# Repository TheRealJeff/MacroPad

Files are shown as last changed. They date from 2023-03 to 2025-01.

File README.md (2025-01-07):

# MacroPad
This page outlines the MacroPad V1 keyboard project. This keyboard is a custom made 4x3 (rxc) with hotswap MX style switches based on the ATMEGA32U4 MCU platform. It is powered by a built-in USB-C connector and uses a custom firmware designed and uploaded with QMK (QMK MSYS and QMK Toolbox). All the required files for PCB, Mech and Firmware are found here.

- '\PCB': kicad, BOM, GERBERS files
- '\3D': Mech design files
- '\firmware': keymaps, configs and hex files

## PCB Design
The PCB was fully designed with KiCAD 7, uses the keyswitch libraries from [ai03 Custom Keyboard](https://wiki.ai03.com/books/pcb-design) and is based on the design from [Masterzen's Blog](https://www.masterzen.fr/2020/05/03/designing-a-keyboard-part-1/).

The keyboard uses an ATMEGA32U4 to receive inputs from a 4x3 key switch matrix. The keyboard uses a USB-C over a USB 2.0 interface for power and data. The switches have Kailh hot swap sockets for easy swapping of the key switches.

## Mech Design
The keyboard has a basic enclosure designed to mainly give it a flat support for testing. It is mounted with 4 M2.5x4mm screws for stability. Currently, the key switches are only retained by the hot swap sockets.

## Firmware
QMK was used for the custom keymap (key switch layout).  Currently, the layout has the following keymap:
| ESC | DEL | 0 |
|-----|-----|---|
| 7 | 8 | 9 |
| 4 | 5 | 6 |
| 1 | 2 | 3 |

### Keyboard Programming
Download QMK MSYS and QMK Toolbox. Open QMK MSYS and follow the on screen instructions to download the necessary repos and drivers.

The `firmware\macropadv1` folder must be put in the `qmk_firmware\keyboards` folder downloaded and installed by QMK MSYS.

To create a new keymap, simply make a new folder in `macropadv1\keymap`, copy the default keymap file and modify it. In QMK MSYS, use the command `qmk compile -kb <keyboard> -km <keymap>` with the selected `keyboard` and `keymap`.

To upload the created `.hex` file, use QMK Toolbox. Connect the keyboard, and press on the reset button. The Toolbox window should display a "DFU Mode" message. At this point, select the `.hex` and flash the keyboard.

## Future Work
Future revisions will have the following updates:
- Use the RP2040 MCU
- LEDs
- Different key matrices
	- 1x2 for OSU
	- Numpad
	- TKL
	- Split keyboard layout (see ZSA Moonlander)
	- Alice Layout
- Better software update for keymaps
- Redesigned enclosure for plate mount switches

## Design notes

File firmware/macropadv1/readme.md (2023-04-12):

# macropadv1

macropadv1

*A short description of the keyboard/project*

* Keyboard Maintainer: [Jeffrey](https://github.com/TheRealJeff)
* Hardware Supported: *The PCBs, controllers supported*
* Hardware Availability: *Links to where you can find this hardware*

Make example for this keyboard (after setting up your build environment):

    make macropadv1:default

Flashing example for this keyboard:

    make macropadv1:default:flash

See the [build environment setup](https://docs.qmk.fm/#/getting_started_build_tools) and the [make instructions](https://docs.qmk.fm/#/getting_started_make_guide) for more information. Brand new to QMK? Start with our [Complete Newbs Guide](https://docs.qmk.fm/#/newbs).

## Bootloader

Enter the bootloader in 3 ways:

* **Bootmagic reset**: Hold down the key at (0,0) in the matrix (usually the top left key or Escape) and plug in the keyboard
* **Physical reset button**: Briefly press the button on the back of the PCB - some may have pads you must short instead
* **Keycode in layout**: Press the key mapped to `QK_BOOT` if it is available

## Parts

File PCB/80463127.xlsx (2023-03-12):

# | QUANTITY | PART NUMBER | MANUFACTURER PART NUMBER | DESCRIPTION | CUSTOMER REFERENCE | BACKORDER | UNIT PRICE | EXTENDED PRICE
1 | 5 | 478-CX3225SB16000D0GZJC1CT-ND | CX3225SB16000D0GZJC1 | CRYSTAL 16.0000MHZ 8PF SMD | Y1 | 0 | 0.95 | 4.75
2 | 5 | 2073-USB4105-GF-ACT-ND | USB4105-GF-A | CONN RCP USB2.0 TYP C 24P SMD RA | USB1 | 0 | 1.19 | 5.95
3 | 3 | ATMEGA32U4-AURCT-ND | ATMEGA32U4-AUR | IC MCU 8BIT 32KB FLASH 44TQFP | U1 | 0 | 9.7 | 29.10
4 | 5 | CKN12221-1-ND | PTS526 SK15 SMTR2 LFS | TACT 5.2 X 5.2, 1.5 MM H, 260GF, | SW1 | 0 | 0.19 | 0.95
5 | 20 | 311-22ARCT-ND | RC0805JR-0722RL | RES 22 OHM 5% 1/8W 0805 | R3, R4 | 0 | 0.044 | 0.88
6 | 20 | 311-5.1KARCT-ND | RC0805JR-075K1L | RES 5.1K OHM 5% 1/8W 0805 | R2, R6 | 0 | 0.044 | 0.88
7 | 20 | 311-10KARCT-ND | RC0805JR-0710KL | RES 10K OHM 5% 1/8W 0805 | R1, R5 | 0 | 0.044 | 0.88
8 | 5 | 507-1803-1-ND | 0ZCJ0050AF2E | PTC RESET FUSE 24V 500MA 1206 | F1 | 0 | 0.346 | 1.73
9 | 5 | 1727-3884-1-ND | PRTR5V0U2X,215 | TVS DIODE 5.5VWM SOT143B | D13 | 0 | 0.75 | 3.75
10 | 100 | 1N4148WTPMSCT-ND | 1N4148W-TP | DIODE GEN PURP 100V 150MA SOD123 | D1-D12 | 0 | 0.0851 | 8.51
11 | 5 | 1276-6455-1-ND | CL21A106KOQNNNG | CAP CER 10UF 16V X5R 0805 | C8 | 0 | 0.15 | 0.75
12 | 20 | 1276-1003-1-ND | CL21B104KBCNNNC | CAP CER 0.1UF 50V X7R 0805 | C4, C5, C6, C7 | 0 | 0.065 | 1.30
13 | 5 | 1276-1066-1-ND | CL21B105KAFNNNE | CAP CER 1UF 25V X7R 0805 | C3 | 0 | 0.15 | 0.75
14 | 10 | 1276-1047-1-ND | CL21C220JBANNNC | CAP CER 22PF 50V C0G/NP0 0805 | C1, C2 | 0 | 0.069 | 0.69
15 | 2 | 1528-4958-ND | 4958 | KAILH SW SKTS FOR MX-COMP 1=20PC | MX1-MX12 | 0 | 7.27 | 14.54
16 | 2 | 1528-5111-ND | 5111 | BLK KAILH CHOC SLIM KEY CAP 1=10 | MX1-MX12 | 0 | 5.87 | 11.74
17 | 2 | 1528-4954-ND | 4954 | KAILH MECHANICAL KEY SWITCHES - | MX1-MX12 | 0 | 10.88 | 21.76

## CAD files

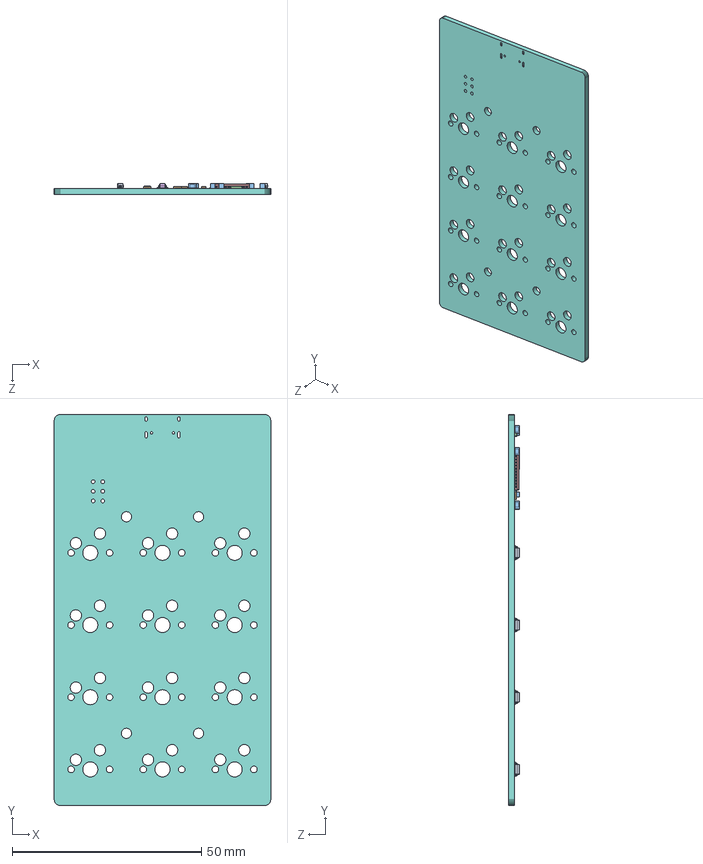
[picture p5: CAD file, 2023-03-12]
3D/MacroPad.SLDASM
57.2 x 103.2 x 2.88 mm
SOLID.step x 12
SOLID-0.step x 6
SOLID-1.step x 8
SOLID-2.step
SOLID-3.step
SOLID-4.step
SOLID-5.step
PCB.step

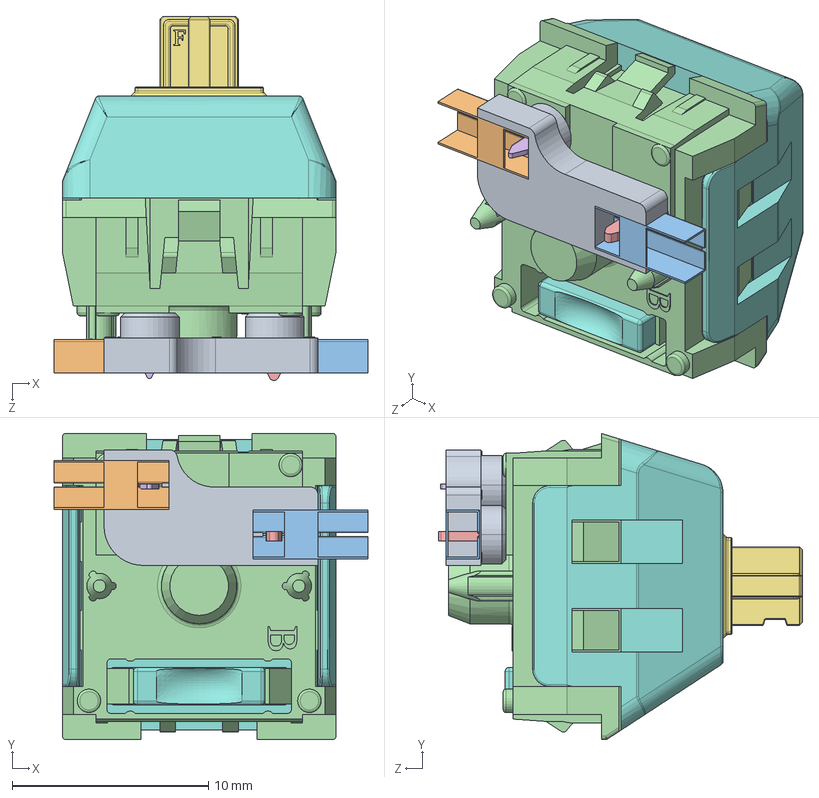
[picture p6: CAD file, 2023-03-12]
3D/HotSwap_Switch_Socket.SLDASM
16.0 x 15.6 x 18.5 mm
Kailh Hotswap MX(2)^Kailh Hotswap MX(2)_Kailh Hotswap MX
Kailh Hotswap MX Inlay^Kailh Hotswap MX(2)_Kailh Hotswap MX
Kailh Hotswap MX Inlay 2^Kailh Hotswap MX(2)_Kailh Hotswap MX
Housing.step
ThickContact.step
SpringContact.step
Stem.step
Lid.step

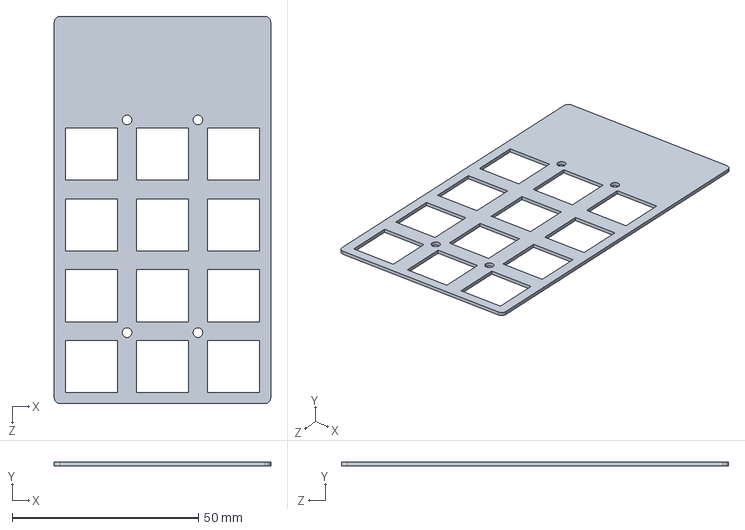
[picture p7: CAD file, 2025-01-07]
3D/MacroPadV2.SLDPRT
58.2 x 1.00 x 104.0 mm

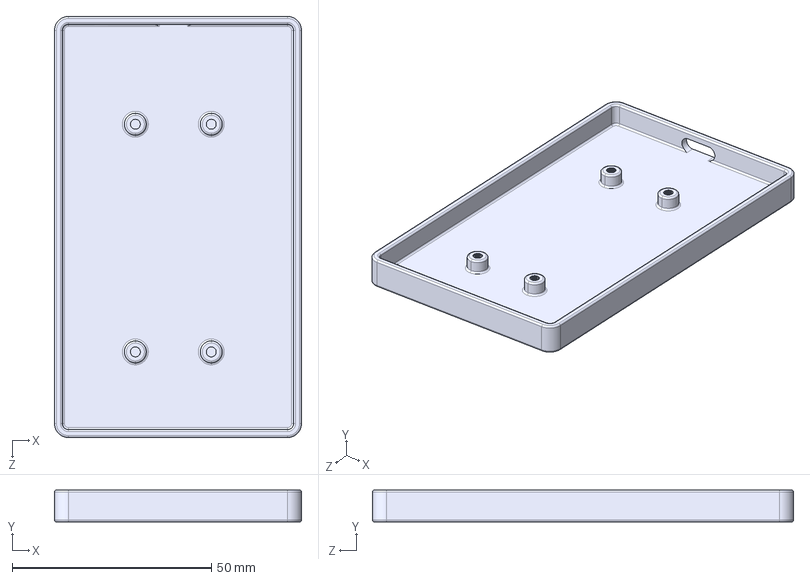
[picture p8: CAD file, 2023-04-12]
3D/MacroPadEnclosure.STEP
62.0 x 8.00 x 105.7 mm

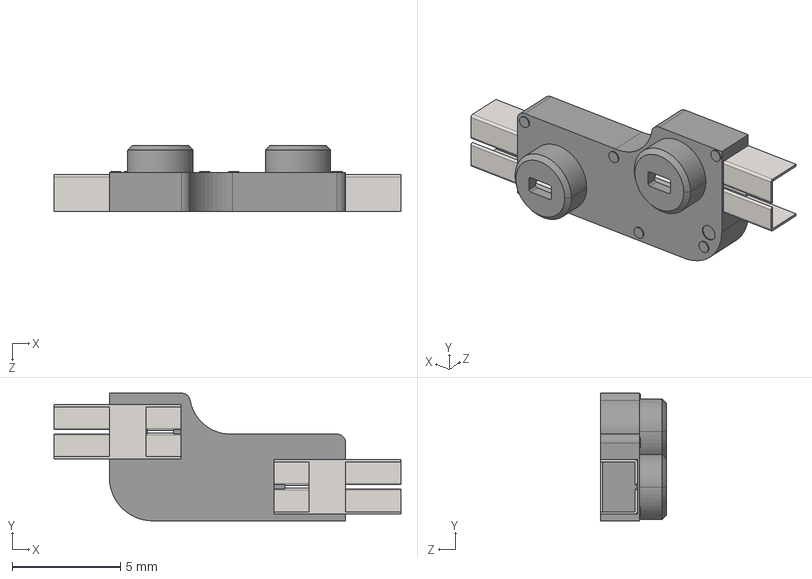
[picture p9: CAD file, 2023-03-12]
3D/Kailh Hotswap MX.step
16.0 x 5.89 x 3.05 mm
Kailh Hotswap MX
Kailh Hotswap MX Inlay
Kailh Hotswap MX Inlay 2

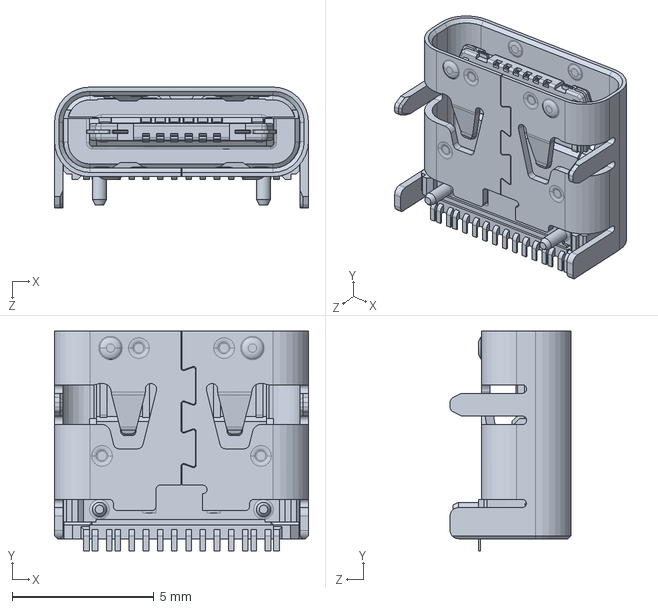
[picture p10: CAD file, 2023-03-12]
3D/User Library-USB - C.SLDPRT
8.95 x 7.75 x 4.26 mm

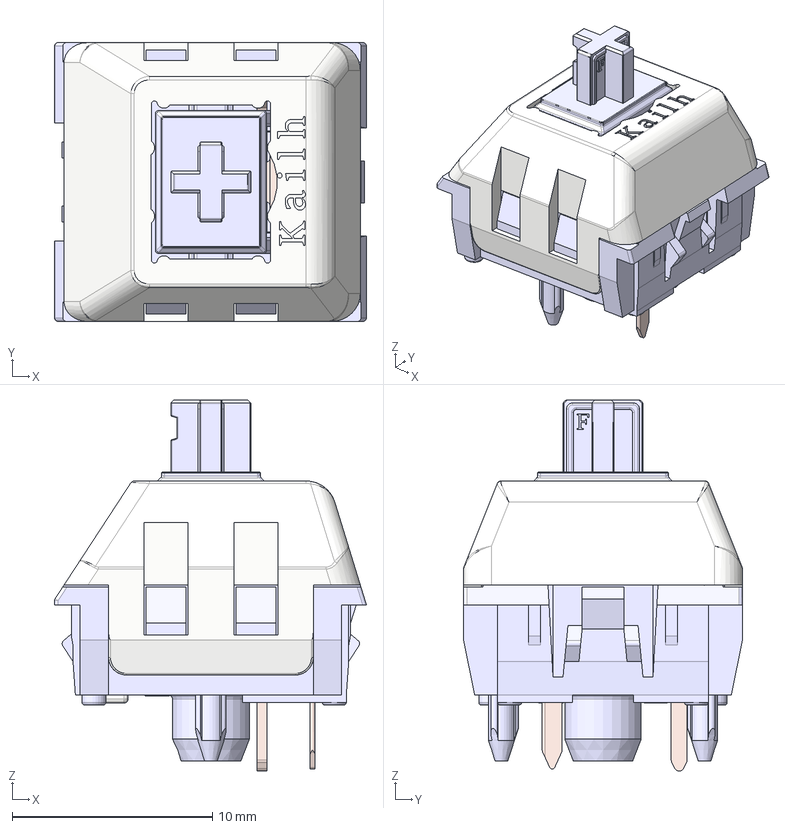
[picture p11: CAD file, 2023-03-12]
3D/Kailh Polia.step
15.6 x 14.0 x 18.5 mm
Housing
ThickContact
SpringContact
Stem
Lid

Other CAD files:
3D/Kailh Hotswap MX.SLDASM
3D/Kailh Polia.SLDASM
3D/MacroPadEnclosure.SLDPRT
3D/MacroPadEnclosure.STL

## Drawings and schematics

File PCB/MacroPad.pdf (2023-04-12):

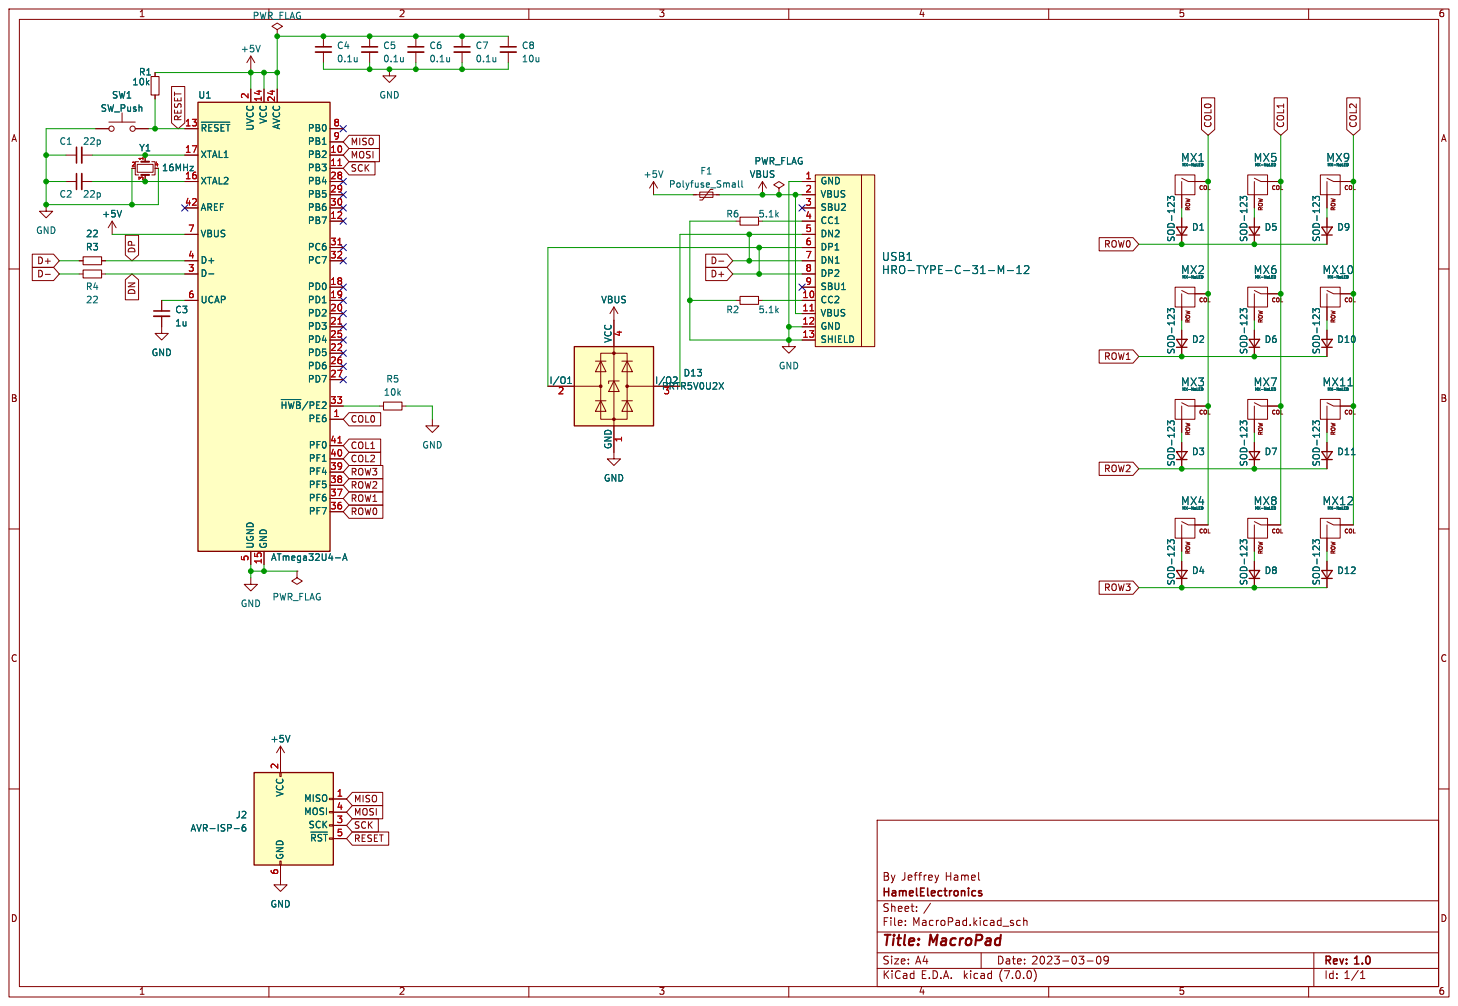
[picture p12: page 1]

COL ROW MX10 MX-NoLED COL ROW MX6 MX-NoLED C7

COL ROW MX5 MX-NoLED GND1

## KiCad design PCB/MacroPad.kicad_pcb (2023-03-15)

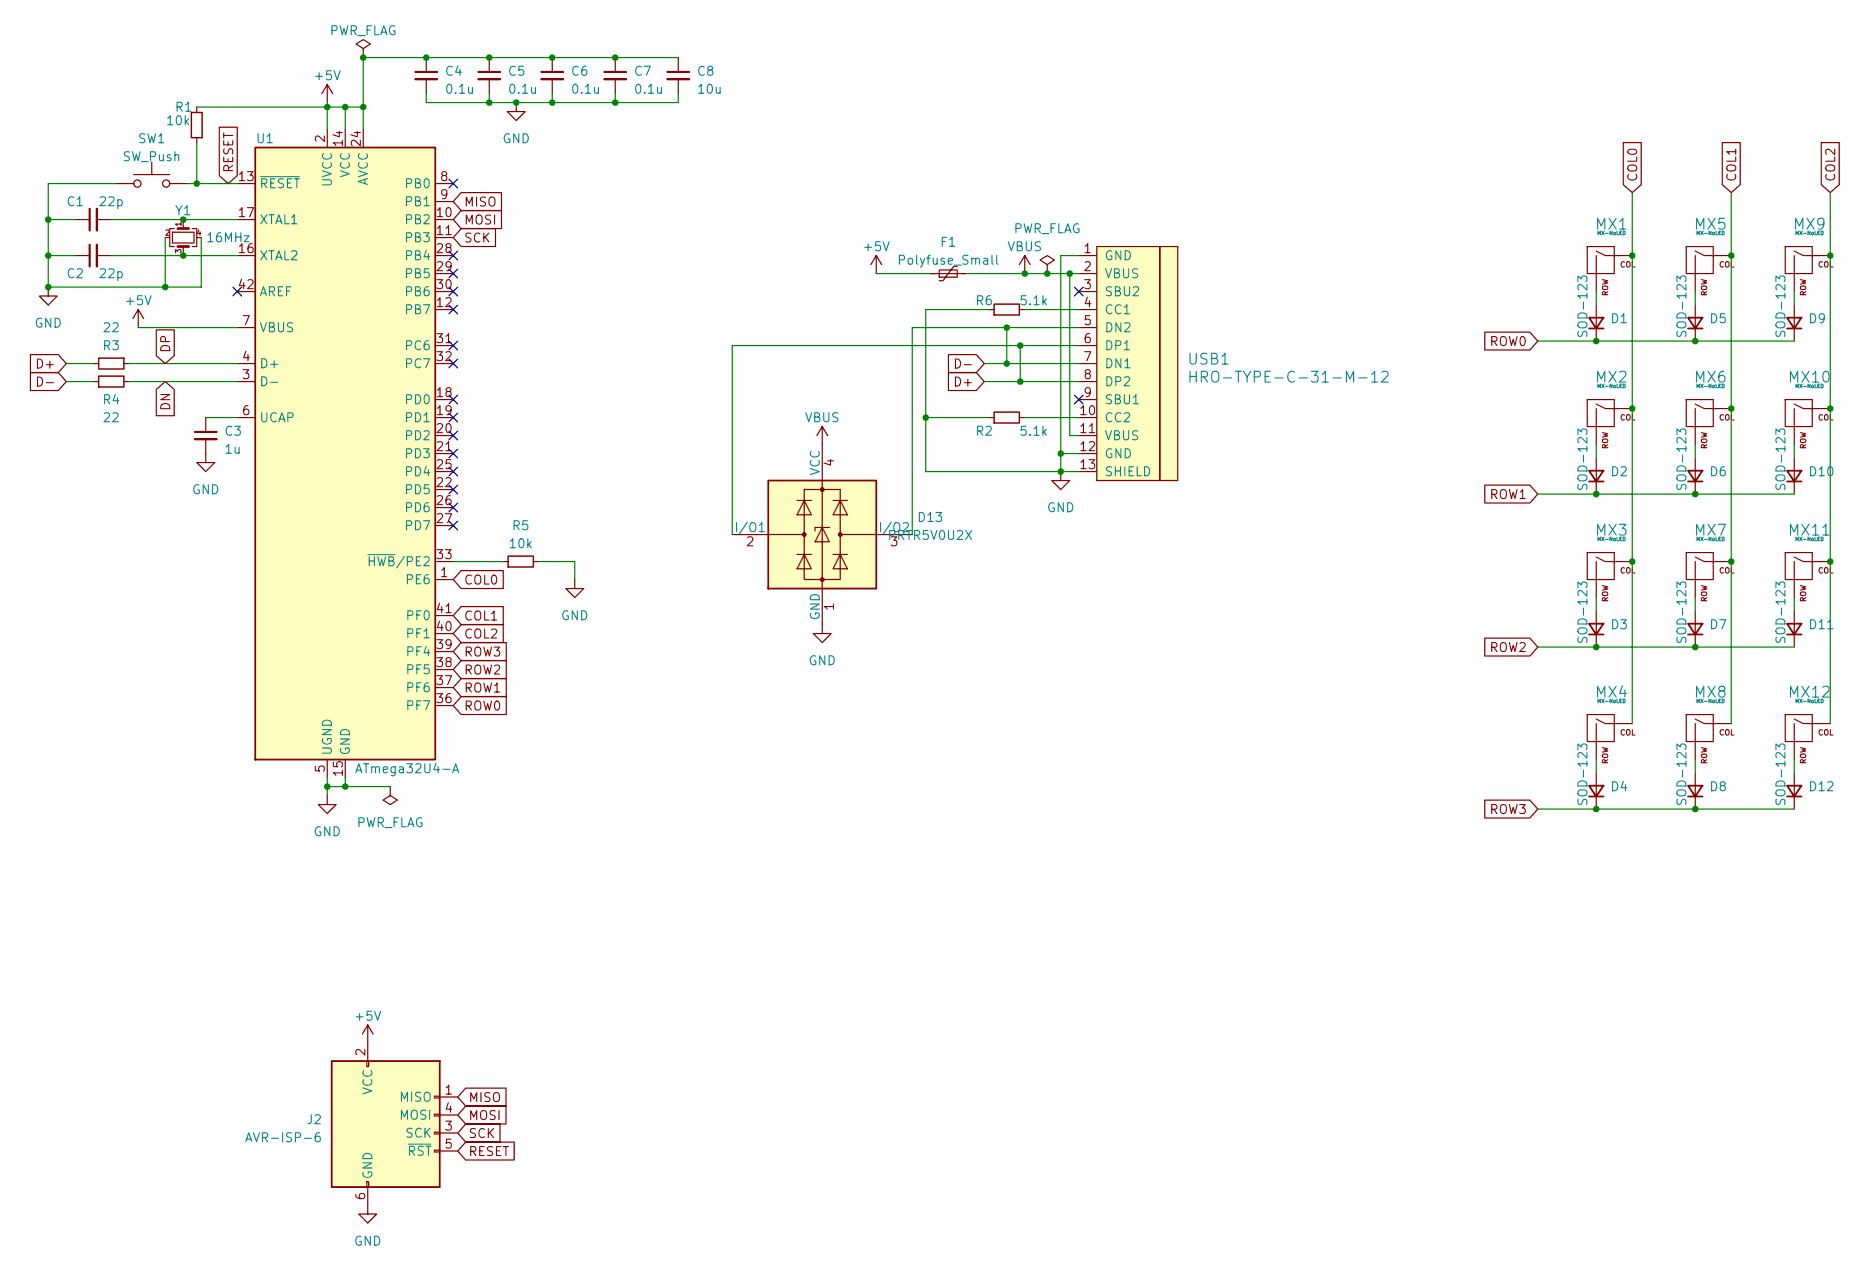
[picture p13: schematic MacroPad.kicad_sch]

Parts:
C1, C2: 22p; C_0805_2012Metric; LCSC C1804
C3: 1u; C_0805_2012Metric; LCSC C116352
C4, C5, C6, C7: 0.1u; C_0805_2012Metric; LCSC C1711
C8: 10u; C_0805_2012Metric; LCSC C307520
D1, D3, D4, D5, D6, D7, D8, D9, D10, D11, D12: SOD-123; D_SOD-123; LCSC C77978
D2: SOD-123; D_SOD-123
D13: PRTR5V0U2X; SOT-143; LCSC C2827688
F1: Polyfuse_Small; Fuse_1206_3216Metric_Pad1.42x1.75mm_HandSolder; LCSC C5118830
J2: AVR-ISP-6; Reset_Pretty-Mask
MX1, MX2, MX3, MX4, MX5, MX6, MX7, MX8, MX9, MX10, MX11, MX12: MX-NoLED; MXOnly-1U-Hotswap; LCSC C5156480
R1, R5: 10k; R_0805_2012Metric; LCSC C100047
R2, R6: 5.1k; R_0805_2012Metric; LCSC C105874
R3, R4: 22; R_0805_2012Metric; LCSC C114231
SW1: SW_Push; SKQG-1155865; LCSC C2689521
U1: ATmega32U4-A; TQFP-44_10x10mm_P0.8mm; LCSC C44854
USB1: HRO-TYPE-C-31-M-12; HRO-TYPE-C-31-M-12-HandSoldering; LCSC C165948
Y1: 16MHz; Crystal_SMD_3225-4Pin_3.2x2.5mm_HandSoldering; LCSC C2650477

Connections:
+5V: C4.1, C5.1, C6.1, C7.1, C8.1, F1.1, J2.2 (VCC), R1.2, U1.2 (UVCC), U1.7 (VBUS), U1.14 (VCC), U1.24 (AVCC), U1.34 (VCC), U1.44 (AVCC)
COL0: MX1.1 (COL), MX2.1 (COL), MX3.1 (COL), MX4.1 (COL), U1.1 (PE6)
COL1: MX5.1 (COL), MX6.1 (COL), MX7.1 (COL), MX8.1 (COL), U1.41 (PF0)
COL2: MX9.1 (COL), MX10.1 (COL), MX11.1 (COL), MX12.1 (COL), U1.40 (PF1)
D+: D13.2 (I/O1), R3.2, USB1.6 (DP1), USB1.8 (DP2)
D-: D13.3 (I/O2), R4.1, USB1.5 (DN2), USB1.7 (DN1)
DN: R4.2, U1.3 (D-)
DP: R3.1, U1.4 (D+)
GND: C1.1, C2.1, C3.2, C4.2, C5.2, C6.2, C7.2, C8.2, D13.1 (GND), J2.6 (GND), R2.1, R5.2, R6.1, SW1.1, U1.5 (UGND), U1.15 (GND), U1.23 (GND), U1.35 (GND), U1.43 (GND), USB1.1 (GND), USB1.12 (GND), USB1.13 (SHIELD), Y1.2, Y1.4
MISO: J2.1 (MISO), U1.9 (PB1)
MOSI: J2.4 (MOSI), U1.10 (PB2)
unnamed: D1.2 (A), MX1.2 (ROW)
unnamed: D2.2 (A), MX2.2 (ROW)
unnamed: D3.2 (A), MX3.2 (ROW)
unnamed: D4.2 (A), MX4.2 (ROW)
unnamed: D5.2 (A), MX5.2 (ROW)
unnamed: D6.2 (A), MX6.2 (ROW)
unnamed: D7.2 (A), MX7.2 (ROW)
unnamed: D8.2 (A), MX8.2 (ROW)
unnamed: D9.2 (A), MX9.2 (ROW)
unnamed: D10.2 (A), MX10.2 (ROW)
unnamed: D11.2 (A), MX11.2 (ROW)
unnamed: D12.2 (A), MX12.2 (ROW)
unnamed: C3.1, U1.6 (UCAP)
unnamed: C1.2, U1.17 (XTAL1), Y1.1
unnamed: C2.2, U1.16 (XTAL2), Y1.3
unnamed: R5.1, U1.33 (~HWB/PE2)
unnamed: R6.2, USB1.4 (CC1)
unnamed: R2.2, USB1.10 (CC2)
RESET: J2.5 (~RST), R1.1, SW1.2, U1.13 (~RESET)
ROW0: D1.1 (K), D5.1 (K), D9.1 (K), U1.36 (PF7)
ROW1: D2.1 (K), D6.1 (K), D10.1 (K), U1.37 (PF6)
ROW2: D3.1 (K), D7.1 (K), D11.1 (K), U1.38 (PF5)
ROW3: D4.1 (K), D8.1 (K), D12.1 (K), U1.39 (PF4)
SCK: J2.3 (SCK), U1.11 (PB3)
VBUS: D13.4 (VCC), F1.2, USB1.2 (VBUS), USB1.11 (VBUS)

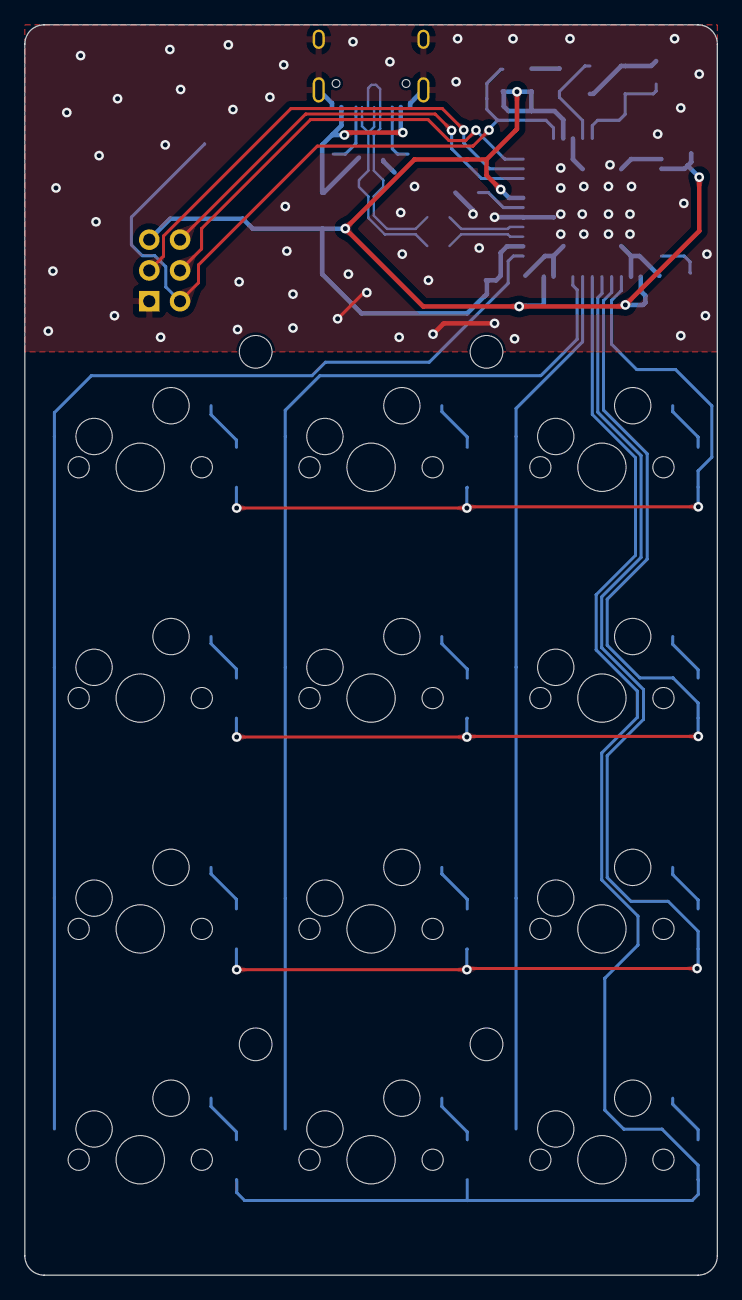
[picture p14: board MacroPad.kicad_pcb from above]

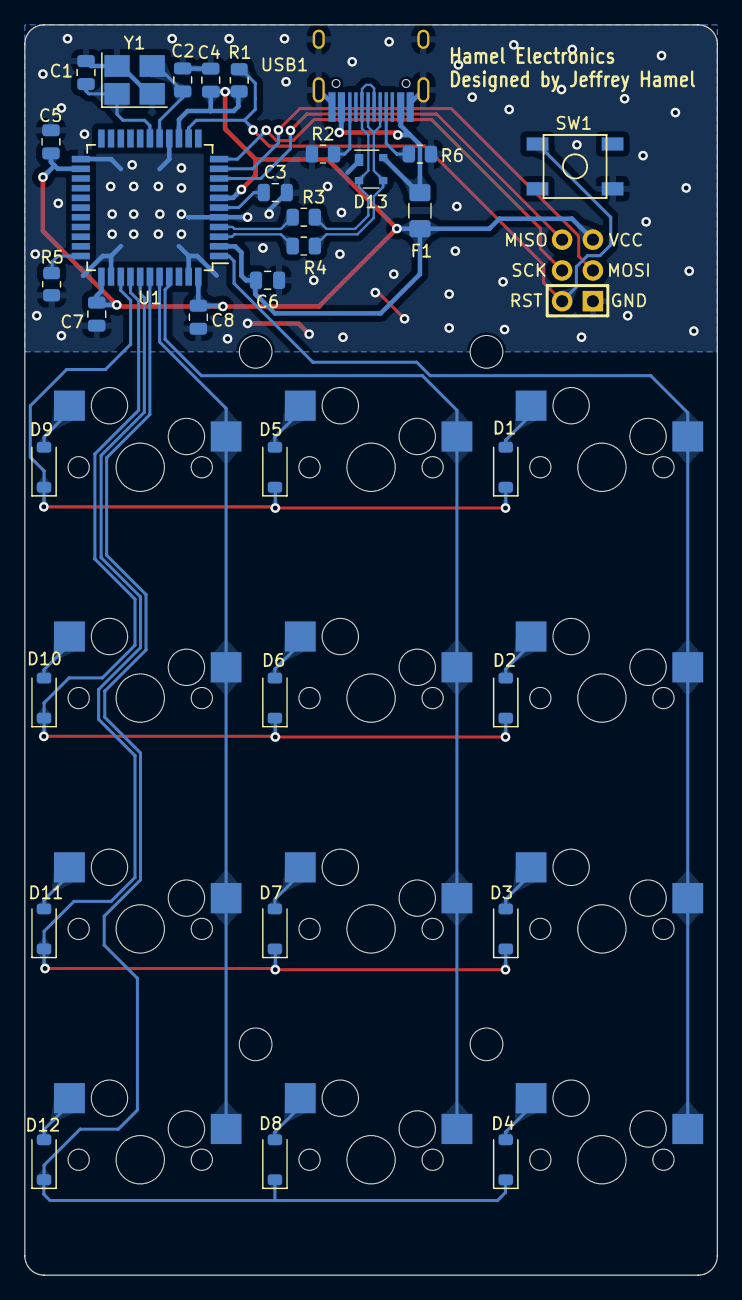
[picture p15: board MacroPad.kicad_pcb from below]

Board: 2 copper layers, 57.2 x 103.2 mm, 45 parts (33 on the bottom side), 36 nets.

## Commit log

2023-03-10 KiCAD project init
    [MacroPad.kicad_pcb, MacroPad.kicad_sch]
2023-03-10 Added schematic and footprint libraries
2023-03-10 Finalized schematic
    [MacroPad.kicad_sch]
2023-03-10 Initial component placement
    [MacroPad.kicad_pcb]
2023-03-11 reworked schematic, added footprint library for USB-C, improved component placement
    [MacroPad.kicad_pcb, MacroPad.kicad_sch]
2023-03-12 finished placement, routing and overall layout
    [MacroPad.kicad_pcb, MacroPad.kicad_sch]
2023-03-12 production files
    [MacroPad-B_Cu.gbl, MacroPad-B_Mask.gbs, MacroPad-B_Paste.gbp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]
2023-03-12 adding cart for later usage
    [80463127.xlsx]
2023-03-12 made macropad enclosure
    [HotSwap_Switch_Socket.SLDASM, Kailh Hotswap MX.SLDASM, Kailh Hotswap MX.step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]
2023-03-15 Added B. Silkscreen notes
    [MacroPad.kicad_pcb]
2023-04-12 added firmware for qmk and updated 3D
    [MacroPadEnclosure.SLDPRT, MacroPadEnclosure.STEP, MacroPadEnclosure.STL]
2023-04-13 force enable NKRO and 1000Hz polling
2025-01-07 restructed folders and updated README
    [80463127.xlsx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]
